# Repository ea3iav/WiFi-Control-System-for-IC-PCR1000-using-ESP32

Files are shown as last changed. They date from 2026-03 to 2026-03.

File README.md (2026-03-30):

# WiFi Control for Icom IC-PCR1000 using ESP32

<div align="center">

**A modern wireless web interface for the Icom IC-PCR1000 communications receiver**

</div>

## Description

This project allows **wireless control** of the classic Icom IC-PCR1000 receiver using an ESP32 microcontroller.

The ESP32 creates its own WiFi Access Point and hosts a clean, responsive web interface optimized for smartphones and tablets. Thanks to WebSockets, all commands are sent and received in real time.

No PC or original software is required — full control directly from your mobile browser.

## ✨ Key Features

- Modern and professional UI with ICOM-inspired design  
- Fully responsive mobile interface  
- Real-time communication via WebSockets  
- Numeric keypad for direct frequency input  
- Graphical S-Meter with color gradient  
- 5 memory slots (save & recall)  
- Volume and Squelch sliders  
- Mode selection (AM, NFM, WFM, USB, LSB, CW)  
- Filter selection (2.8kHz to 230kHz)  
- Toggle functions: NB, AGC, ATT, ANF  
- Automatic receiver initialization  
- Standalone operation  

## 🛠️ Hardware Required

- ESP32 development board  
- Icom IC-PCR1000 receiver  
- **MAX232** level converter (**mandatory**)  
- DB9 serial cable  
- Jumper wires (Dupont)  
- Stable power supply for the PCR1000  

## 🔌 Wiring

### ESP32 → MAX232

| ESP32 | MAX232 |
|---|---|
| GPIO17 (TX) | RX |
| GPIO16 (RX) | TX |
| GND | GND |
| 5V or 3.3V | VCC |

**Important:** TX and RX must be crossed.

### MAX232 → IC-PCR1000 (DB9)

| MAX232 | DB9 Pin |
|---|---|
| TX | Pin 2 (RX) |
| RX | Pin 3 (TX) |
| GND | Pin 5 |
Put a jumper on pins 7-8 on the DB9
## 🚀 Installation

### 1. Arduino IDE Setup

Add the ESP32 board URL in **File → Preferences**:

### 2. Board Selection

**Tools → Board → ESP32 Arduino → ESP32 Dev Module**

### 3. Upload

- Connect the ESP32 via USB  
- Select the correct COM port  
- Click **Upload**

## 📡 How to Connect

1. Power on the ESP32  
2. Connect to the WiFi network:  
   - **SSID**: `prc1000`  
   - **Password**: `12345678`  
3. Open your browser and go to:
        http://192.168.4.1
   
## 🎛️ Interface Overview

- **Frequency**: Tap the large display to open numeric keypad  
- **Tuning**: F+ / F− buttons + Step selector (1kHz to 100kHz)  
- **Modes**: AM • NFM • WFM • USB • LSB • CW  
- **Filters**: 2.8k • 6k • 15k • 50k • 230k  
- **Functions**: NB • AGC • ATT • ANF (toggle)  
- **Audio**: Smooth Volume and Squelch sliders  
- **S-Meter**: Real-time bar with green → yellow → red gradient  
- **Memories**: 5 slots (M1–M5) — Press **M** to save current settings  

## 📋 Important Notes

- The **MAX232** is required. Direct connection from ESP32 to PCR1000 will **not** work.  
- Baud rate: **9600 bps**  
- Verify all wiring before powering on  
- Use a stable 12V power supply for the receiver  

---

**Developed by EA3IAV**

**Disclaimer**

This project is provided for experimental and educational purposes only.

All designs, code, and hardware configurations are shared “as is”, without any guarantees or warranties of any kind, either expressed or implied. The author assumes no responsibility for any damage, malfunction, data loss, injury, or other issues that may arise from the use or misuse of this project.

Users are solely responsible for ensuring that their implementation is safe, appropriate, and compliant with relevant standards and regulations. Working with electronics, power sources (such as batteries), and mechanical components carries inherent risks.

By using this project, you agree that you do so at your own risk.

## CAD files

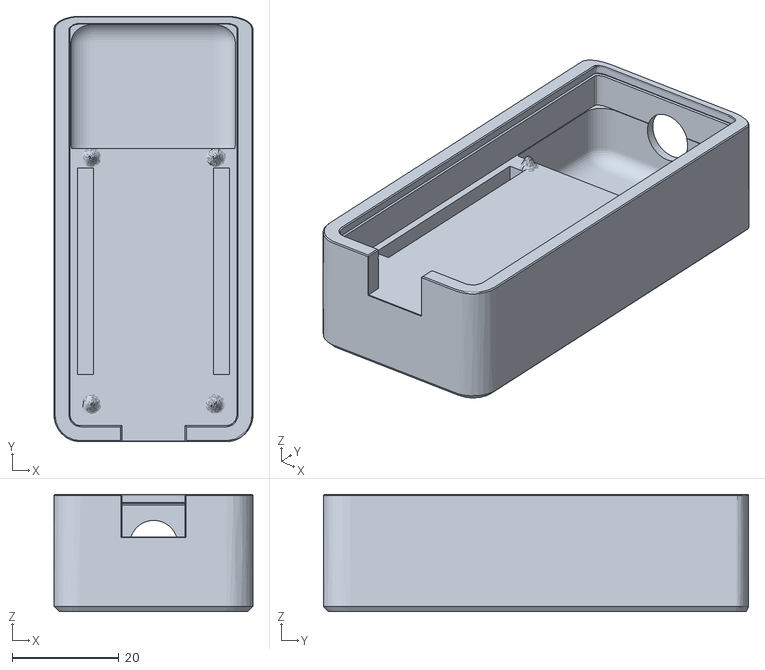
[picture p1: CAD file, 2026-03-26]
esp32 pcr1000 wifi bottom.stl
37.3 x 79.7 x 22.0

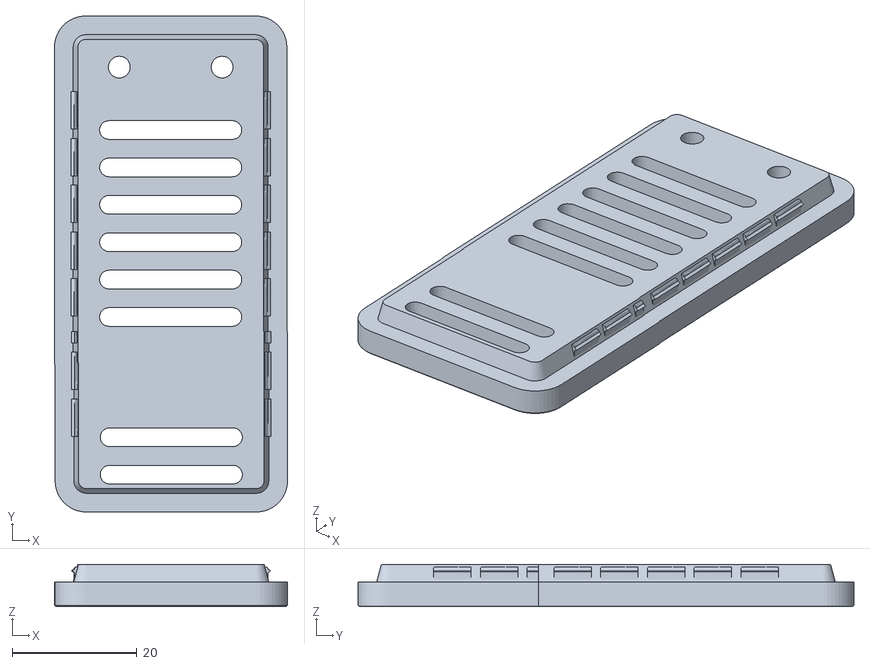
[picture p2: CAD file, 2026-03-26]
esp32 pcr1000 wifi top.stl
37.4 x 79.6 x 6.80

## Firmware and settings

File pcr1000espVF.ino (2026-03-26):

#include <WiFi.h>
#include <WebServer.h>
#include <WebSocketsServer.h>
#include <HardwareSerial.h>

// WIFI AP
const char* ssid = "prc1000";
const char* password = "12345678";

WebServer server(80);
WebSocketsServer webSocket(81);

// PCR1000
HardwareSerial PCR(2);

// ===== ESTADO =====
float frequency = 95.800;
int currentMode = 6;
int currentFilter = 4;

bool NB=false, AGC=false, ATT=false, ANF=false;

// STEP
float stepList[] = {0.001,0.005,0.0125,0.02,0.05,0.1};
int stepIndex = 5;
float step = 0.1;

// MEMORIAS
struct Memory {
  float freq;
  int mode;
  int filter;
};

Memory mem[5];
int memIndex = 0;

// ================= SETUP =================
void setup(){

  Serial.begin(115200);

  WiFi.softAP(ssid, password);

  PCR.begin(9600, SERIAL_8N1, 16, 17);
  delay(2000);

  initPCR();

  server.on("/", handleRoot);
  server.begin();

  webSocket.begin();
  webSocket.onEvent(webSocketEvent);
}

// ================= LOOP =================
void loop(){

  server.handleClient();
  webSocket.loop();

  static unsigned long t=0;
  if(millis()-t>2000){
    PCR.println("H800");
    t=millis();
  }

  static unsigned long smT=0;
  if(millis()-smT>400){
    readSMeter();
    smT=millis();
  }
}

// ================= INIT =================
void initPCR(){

  PCR.println("H101"); delay(800);
  PCR.println("G301"); delay(800);
  PCR.println("H800"); delay(500);

  PCR.println("J4026"); delay(500);
  PCR.println("J4100"); delay(500);

  PCR.println("J4501"); delay(300);
  PCR.println("J4600"); delay(300);
  PCR.println("J4700"); delay(300);

  sendFrequency();
}

// ================= FRECUENCIA =================
void sendFrequency(){

  long hz=(long)(frequency*1000000);
  int mhz=hz/1000000;
  int hz_part=hz%1000000;

  char cmd[32];
  sprintf(cmd,"K0%04d%06d%02d%02d00",mhz,hz_part,currentMode,currentFilter);

  PCR.print(cmd); PCR.print("\r\n");

  webSocket.broadcastTXT("FREQ:"+String(frequency,3));
}

// ================= S-METER =================
void readSMeter(){

  PCR.print("I1?\r\n");
  delay(10);

  String data="";

  while(PCR.available()){
    data+=(char)PCR.read();
  }

  int pos=data.indexOf("I1");

  if(pos!=-1 && data.length()>=pos+4){

    String hex=data.substring(pos+2,pos+4);
    int val=strtol(hex.c_str(),NULL,16);

    int sm=map(val,0x60,0x90,0,9);
    sm=constrain(sm,0,9);

    webSocket.broadcastTXT("SM:"+String(sm));
  }
}

// ================= MEM =================
void saveMemory(){
  mem[memIndex].freq = frequency;
  mem[memIndex].mode = currentMode;
  mem[memIndex].filter = currentFilter;

  memIndex++;
  if(memIndex>=5) memIndex=0;
}

void loadMemory(int i){
  frequency = mem[i].freq;
  currentMode = mem[i].mode;
  currentFilter = mem[i].filter;
  sendFrequency();
}

// ================= OPCIONES =================
void sendOptions(){

  PCR.println(AGC ? "J4501" : "J4500");
  PCR.println(NB  ? "J4601" : "J4600");
  PCR.println(ATT ? "J4701" : "J4700");
}

// ================= WS =================
void webSocketEvent(uint8_t num, WStype_t type, uint8_t * payload, size_t length){

  if(type == WStype_TEXT){

    String msg = (char*)payload;

    if(msg=="UP"){ frequency+=step; sendFrequency(); }
    if(msg=="DOWN"){ frequency-=step; sendFrequency(); }

    if(msg.startsWith("STEP:")){
      stepIndex = msg.substring(5).toInt();
      step = stepList[stepIndex];
    }

    if(msg.startsWith("MODE:")){
      currentMode = msg.substring(5).toInt();
      sendFrequency();
    }

    if(msg.startsWith("VOL:")){
      char cmd[10];
      sprintf(cmd,"J40%02X",msg.substring(4).toInt());
      PCR.println(cmd);
    }

    if(msg.startsWith("SQL:")){
      char cmd[10];
      sprintf(cmd,"J41%02X",msg.substring(4).toInt());
      PCR.println(cmd);
    }

    if(msg.startsWith("FILTER:")){
      currentFilter = msg.substring(7).toInt();
      sendFrequency();
    }

    if(msg.startsWith("TOGGLE:")){
      String t=msg.substring(7);
      if(t=="NB") NB=!NB;
      if(t=="AGC") AGC=!AGC;
      if(t=="ATT") ATT=!ATT;
      if(t=="ANF") ANF=!ANF;
      sendOptions();
    }

    if(msg.startsWith("FREQ:")){
      frequency = msg.substring(5).toFloat();
      sendFrequency();
    }

    if(msg=="SAVE"){ saveMemory(); }
    if(msg.startsWith("LOAD:")) loadMemory(msg.substring(5).toInt());
  }
}

// ================= WEB =================
void handleRoot(){

server.send(200,"text/html",R"rawliteral(

<!DOCTYPE html>
<html>
<head>
<meta name="viewport" content="width=device-width, initial-scale=1, user-scalable=no">

<style>

body{background:#0b0b0b;color:#00ff88;font-family:Arial;margin:0;text-align:center;touch-action:manipulation;}

.freq{font-size:48px;padding:15px 0;font-weight:bold;color:white;}

.smeter{width:70%;margin:10px auto;height:14px;border-radius:8px;background:black;}
.fill{height:100%;width:0%;border-radius:8px;background:linear-gradient(to right,#0f0,yellow,red);}

.row{display:flex;justify-content:space-between;padding:5px;}

.btn{flex:1;margin:4px;padding:14px;border-radius:10px;background:#1c1c1c;color:#ccc;border:1px solid #333;}
.active{color:red;border-color:red;}

.memfull{color:red;}
.memsel{border:2px solid red;}
.mpressed{background:red;color:black;}

.tune{
  display:flex;
  justify-content:center;
  gap:10px;
}

.fbtn{
  width:100px;
  height:100px;
  border-radius:20px;
  background:#d0d0d0;
  border:2px solid white;
  color:black;
  font-weight:bold;
  font-size:28px;   /* 👈 más grande */
  box-shadow:0 3px 6px rgba(0,0,0,0.5);
}

.step{
  width:65px;     /* antes 110px */
  height:65px;
  border-radius:50%;
  background:#d0d0d0;
  border:2px solid white;
  color:black;
  font-weight:bold;
  box-shadow:0 3px 6px rgba(0,0,0,0.5);
  font-size:12px;
}

.slider{
  width:90%;
  -webkit-appearance:none;
  background:transparent;
}

.slider::-webkit-slider-runnable-track{
  height:8px;
  background:red;
  border-radius:5px;
}

.slider::-webkit-slider-thumb{
  -webkit-appearance:none;
  width:18px;height:18px;
  border-radius:50%;
  background:white;
  margin-top:-5px;
}

#keypad{
  position:fixed;top:0;left:0;width:100%;height:100%;
  background:black;display:none;
}

.keygrid{
  display:grid;
  grid-template-columns:repeat(3,1fr);
  gap:10px;
  padding:10px;
}

.key{height:80px;font-size:24px;border-radius:12px;background:#222;color:white;}
.ok{background:white;color:black;}
.clear{background:#aa3333;}

.watermark{margin-top:25px;font-size:10px;color:#555;}

</style>
</head>

<body>

<div class="freq" onclick="openKeypad()" id="freq">95.800</div>
<div style="color:white;font-size:12px;margin-top:-10px;">IC-PCR1000</div>

<div class="smeter"><div id="sm" class="fill"></div></div>

<div class="tune">
<button class="fbtn" onclick="freqDown()">F-</button>
<button class="step" onclick="changeStep()" id="stepBtn">100k</button>
<button class="fbtn" onclick="freqUp()">F+</button>
</div>

<div class="row">
<button class="btn" id="Mbtn" ontouchstart="mPress()" ontouchend="mRelease()" onclick="save()">M</button>
<button class="btn" id="M0" onclick="loadMem(0)">M1</button>
<button class="btn" id="M1" onclick="loadMem(1)">M2</button>
<button class="btn" id="M2" onclick="loadMem(2)">M3</button>
<button class="btn" id="M3" onclick="loadMem(3)">M4</button>
<button class="btn" id="M4" onclick="loadMem(4)">M5</button>
</div>

<div class="row">
<button id="mode2" class="btn" onclick="mode(2)">AM</button>
<button id="mode5" class="btn" onclick="mode(5)">NFM</button>
<button id="mode6" class="btn active" onclick="mode(6)">WFM</button>
<button id="mode1" class="btn" onclick="mode(1)">USB</button>
<button id="mode0" class="btn" onclick="mode(0)">LSB</button>
<button id="mode3" class="btn" onclick="mode(3)">CW</button>
</div>

<div class="row">
<button id="NB" class="btn" onclick="tog('NB')">NB</button>
<button id="AGC" class="btn" onclick="tog('AGC')">AGC</button>
<button id="ATT" class="btn" onclick="tog('ATT')">ATT</button>
<button id="ANF" class="btn" onclick="tog('ANF')">ANF</button>
</div>

<div class="row">
<button id="F0" class="btn" onclick="filter(0)">2.8k</button>
<button id="F1" class="btn" onclick="filter(1)">6k</button>
<button id="F2" class="btn" onclick="filter(2)">15k</button>
<button id="F3" class="btn" onclick="filter(3)">50k</button>
<button id="F4" class="btn active" onclick="filter(4)">230k</button>
</div>

<div style="color:white;">VOL<br><input type="range" min="0" max="255" value="38" class="slider" oninput="vol(this.value)"></div>
<div style="color:white;">SQL<br><input type="range" min="0" max="255" value="0" class="slider" oninput="sql(this.value)"></div>

<div id="keypad">
<h1 id="display" style="color:white;">0</h1>

<div class="keygrid">
<button class="key" onclick="add('1')">1</button>
<button class="key" onclick="add('2')">2</button>
<button class="key" onclick="add('3')">3</button>
<button class="key" onclick="add('4')">4</button>
<button class="key" onclick="add('5')">5</button>
<button class="key" onclick="add('6')">6</button>
<button class="key" onclick="add('7')">7</button>
<button class="key" onclick="add('8')">8</button>
<button class="key" onclick="add('9')">9</button>
<button class="key" onclick="add('.')">.</button>
<button class="key" onclick="add('0')">0</button>
<button class="key clear" onclick="clearInput()">C</button>
</div>

<div class="row">
<button class="btn ok" onclick="sendFreq()">OK</button>
<button class="btn clear" onclick="closeKeypad()">EXIT</button>
</div>
</div>

<div class="watermark">Developed by EA3IAV</div>

<script>

let ws = new WebSocket("ws://" + location.hostname + ":81");

ws.onmessage = function(e){
  if(e.data.startsWith("FREQ:")){
    document.getElementById("freq").innerText = e.data.substring(5);
  }
  if(e.data.startsWith("SM:")){
    let v=parseInt(e.data.substring(3));
    document.getElementById("sm").style.width = v<=0 ? "0%" : (v*11)+"%";
  }
};

function freqUp(){ clearMemSel(); ws.send("UP"); }
function freqDown(){ clearMemSel(); ws.send("DOWN"); }

function vol(v){ ws.send("VOL:"+v); }
function sql(v){ ws.send("SQL:"+v); }

function filter(f){
  ws.send("FILTER:"+f);
  for(let i=0;i<5;i++) document.getElementById("F"+i).classList.remove("active");
  document.getElementById("F"+f).classList.add("active");
}

function tog(t){
  ws.send("TOGGLE:"+t);
  document.getElementById(t).classList.toggle("active");
}

function mode(m){
  ws.send("MODE:"+m);
  document.querySelectorAll("[id^='mode']").forEach(b=>b.classList.remove("active"));
  document.getElementById("mode"+m).classList.add("active");
}

let memPtr=0;

function mPress(){ document.getElementById("Mbtn").classList.add("mpressed"); }
function mRelease(){ document.getElementById("Mbtn").classList.remove("mpressed"); }

function save(){
  ws.send("SAVE");
  document.getElementById("M"+memPtr).classList.add("memfull");
  clearMemSel();
  document.getElementById("M"+memPtr).classList.add("memsel");
  memPtr++;
  if(memPtr>4) memPtr=0;
}

function loadMem(i){
  ws.send("LOAD:"+i);
  clearMemSel();
  document.getElementById("M"+i).classList.add("memsel");
}

function clearMemSel(){
  for(let i=0;i<5;i++) document.getElementById("M"+i).classList.remove("memsel");
}

let input="";

function openKeypad(){ document.getElementById("keypad").style.display="block"; }
function closeKeypad(){ document.getElementById("keypad").style.display="none"; input=""; }

function add(v){
  input+=v;
  document.getElementById("display").innerText=input;
}

function clearInput(){
  input="";
  document.getElementById("display").innerText="0";
}

function sendFreq(){
  ws.send("FREQ:"+input);
  closeKeypad();
  clearMemSel();
}

let stepIndex=5;
let stepLabels=["1k","5k","12.5k","20k","50k","100k"];

function changeStep(){
  stepIndex++;
  if(stepIndex>5) stepIndex=0;

  ws.send("STEP:"+stepIndex);

  document.getElementById("stepBtn").innerText = stepLabels[stepIndex];
}

</script>

</body>
</html>

)rawliteral");
}
